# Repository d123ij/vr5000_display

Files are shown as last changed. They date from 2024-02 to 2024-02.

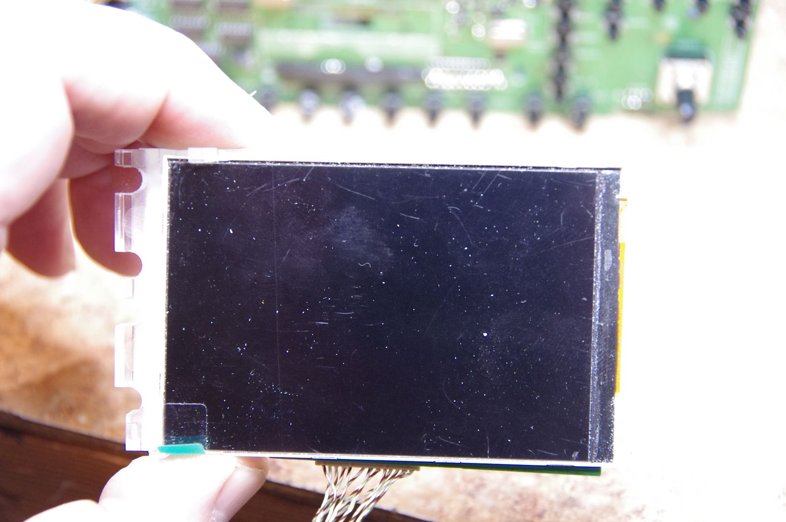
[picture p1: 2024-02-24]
images/IMGP0147 [].JPG

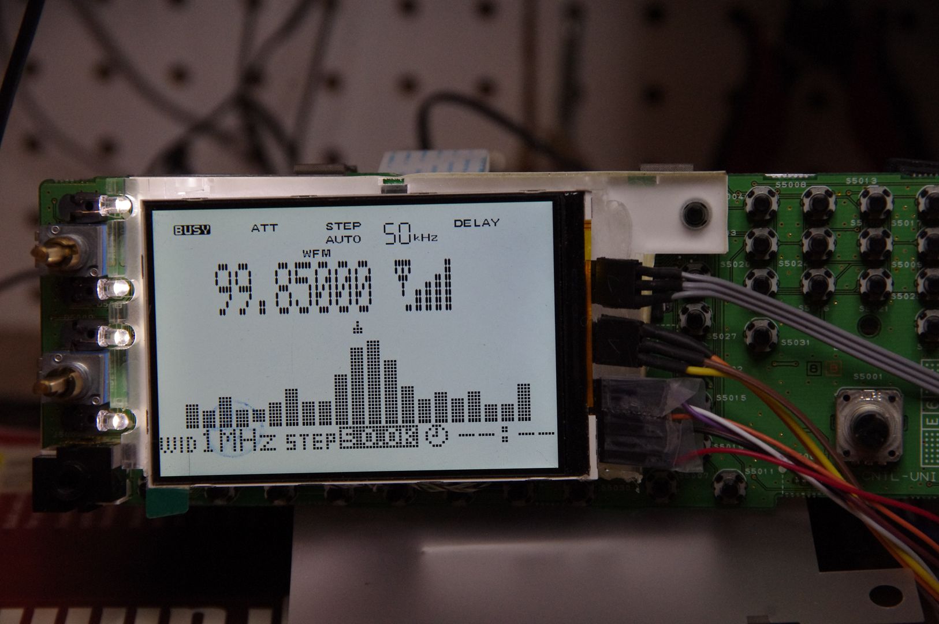
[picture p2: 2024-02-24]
images/IMGP0154 [].JPG

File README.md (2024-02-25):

This project is to create a substitute display unit for Yaesu VR-5000 broad band receiver "famous" for failing LCDs. The design is made possible only because of prior work by kakiralime (this is youtube username). I would not have enough patience to pull this through myself. 
There are three parts to the project:
 - Hardware (PCB)
 - FPGA firmware project
 - RP2040 firmware project

1. PCB project. Pretty simple 2 layer board made with JLCPCB
2. FPGA project is to emulate functionality of NJU6575 IC used in the original LCD and pass data along to the RP2040 that does all the graphics. The vr5000 CPU does use read-modify-write approach when working with the display memory. Therefore, when the original display IC, NJU6575 is removed its buffer has to be simulated. In this project is was done using Lattce LCMXO2-1200HC FPGA ($7). The FPGA has internal flash memory and free tool set is provided from Lattice. It can be programmed using HW-USBN-2A clone from e-bay. The cheapest one at the time of this writing was around $20. In addition to simulating the memory buffer the FPGA also packages and sends data to the rp2040. Communication protocol is one-directional and uses 6 lines all from FPGA to rp2040. There are: CSN, CLK and DATA(3:0). Every transaction has three clock pulses and both edges of the clock are used for the data transfer. Two clocks are used to sent four bytes, the third clock is dummy to make sure rp2040 state machine never get stuck. There is only one command to send page and column number for data transfers. Data transactions are sent one byte per transfer. The FPGA system interface has to handle 5V, which is achieved by using 8 bit level shifter IC to deal with bi-directional data lines. WRN, RDN and A0 signals are input only and dealt with by using a current limiting resistor on the FPGA input. 
3. RP2040 is responsible for displaying data. All the graphic utilities are based on kakiralime's work. I used them pretty much unchanged. The firmware runs on top of FreeRTOS. Communication with the FPGA is done via PIO state machine. rp2040 is a slave, it monitors CSN and CLK signals and inputs data when clock transition is detected. Data are transferred from input FIFOs to memory via two chained DMA channels that operate continuously. I found that using one DMA in conjunction with interrupt is not fast enough and data are lost periodically with that approach. Chaining DMAs solved that. Once data arrived they placed in queue by ISR. One of the background tasks dequeues data and processes incoming commands and data. The data format for the LCD consumption follows the one in kakiralime work to minimize amount of work. I only updated in/out routines for a different CPU and restructured code somewhat. The utilized LCD model is the same, currently ~$10 delivered from AliExpress (I bough it from JR E-Shop). You can see the image from AliExpress in the image section. Programming of the rp2040 was done using debug interface and PI pico module as a debugger. I actually routed debugging connector out of receiver to modify software while operating radio. 
4. This project is not for faint-harted! You should be able to solder QFN packages and trap-door connectors with 0.6 mm pitch. To fit the new unit inside the receiver I reused the original plexiglass block by making a cavity large enough to fit the new PCB, which is fixed to the back of the LCD by sticky tape. Dremel tool is your friend here. The new display dimension is somewhat smaller than original LCD, you can see the space on the right side of the screen unoccupied by the LCD.
5. This design requires two power connections. The 5V power was taken from c5012 as 5v from the LCD connector is there even when the receiver is off. Backlight power was taken from TP5069. The board consumption was around 50-60mA. Backlight current was about 80mA.

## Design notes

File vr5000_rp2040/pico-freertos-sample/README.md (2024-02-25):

# Raspberry Pi Pico Sample application with FreeRTOS

## Introduction

- FreeRTOS kernel library for Pico SDK

## How to make

Pico SDK environment is required.

- Clone this repository with "--recursive" option.
- Type following commands.
    ```
    $ mkdir build
    $ cd build
    $ cmake ..
    $ make
    ```

## License

- MIT (same as FreeRTOS kernel)
  - freertos/ directory
- BSD 3-Clause (same as Pico SDK)
  - others

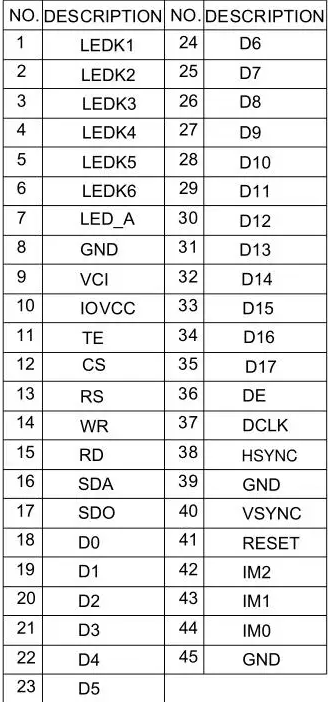
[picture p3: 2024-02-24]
v5000_lcd_rev2_pcb/disp_pinout.png

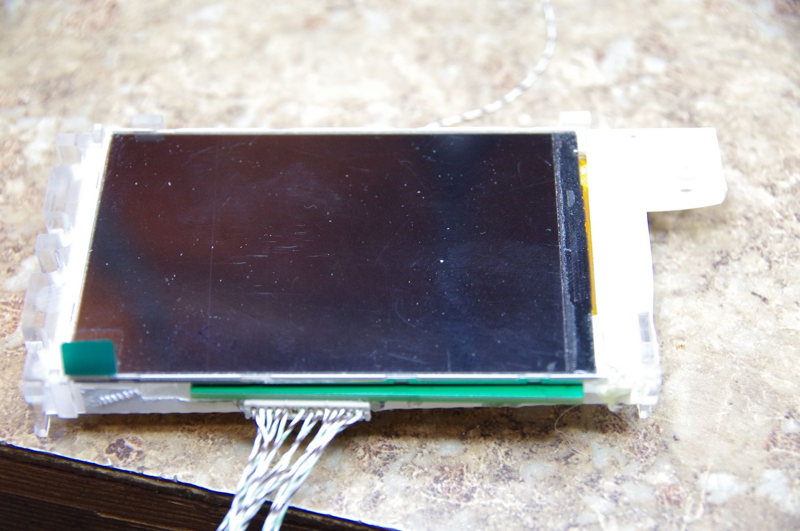
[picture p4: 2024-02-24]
images/IMGP0146 [].JPG

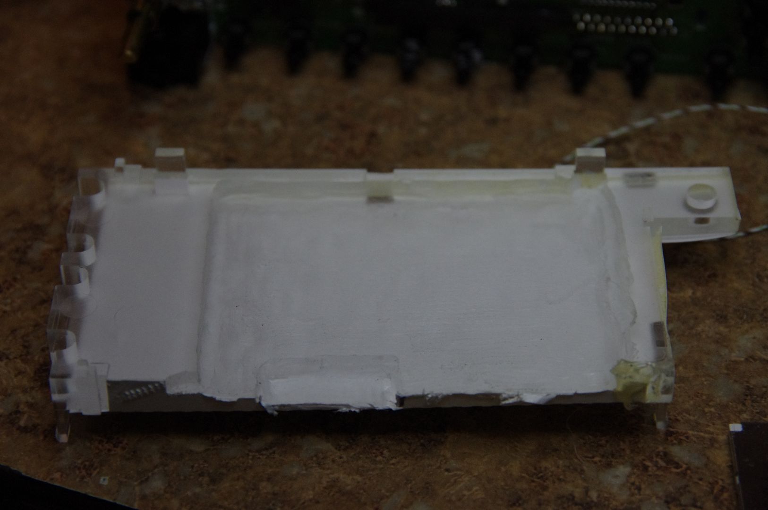
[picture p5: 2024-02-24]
images/IMGP0151 [].JPG

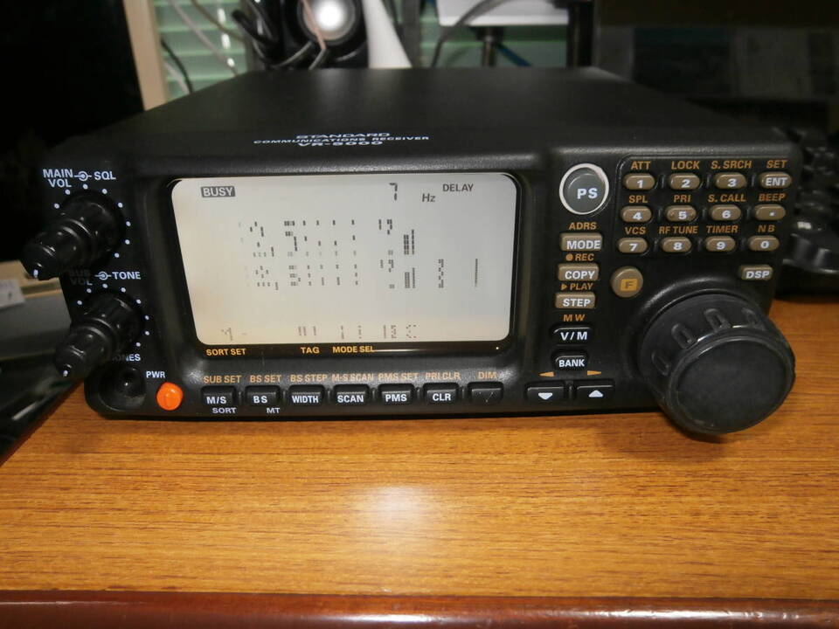
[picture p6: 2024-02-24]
images/s-l960.jpg

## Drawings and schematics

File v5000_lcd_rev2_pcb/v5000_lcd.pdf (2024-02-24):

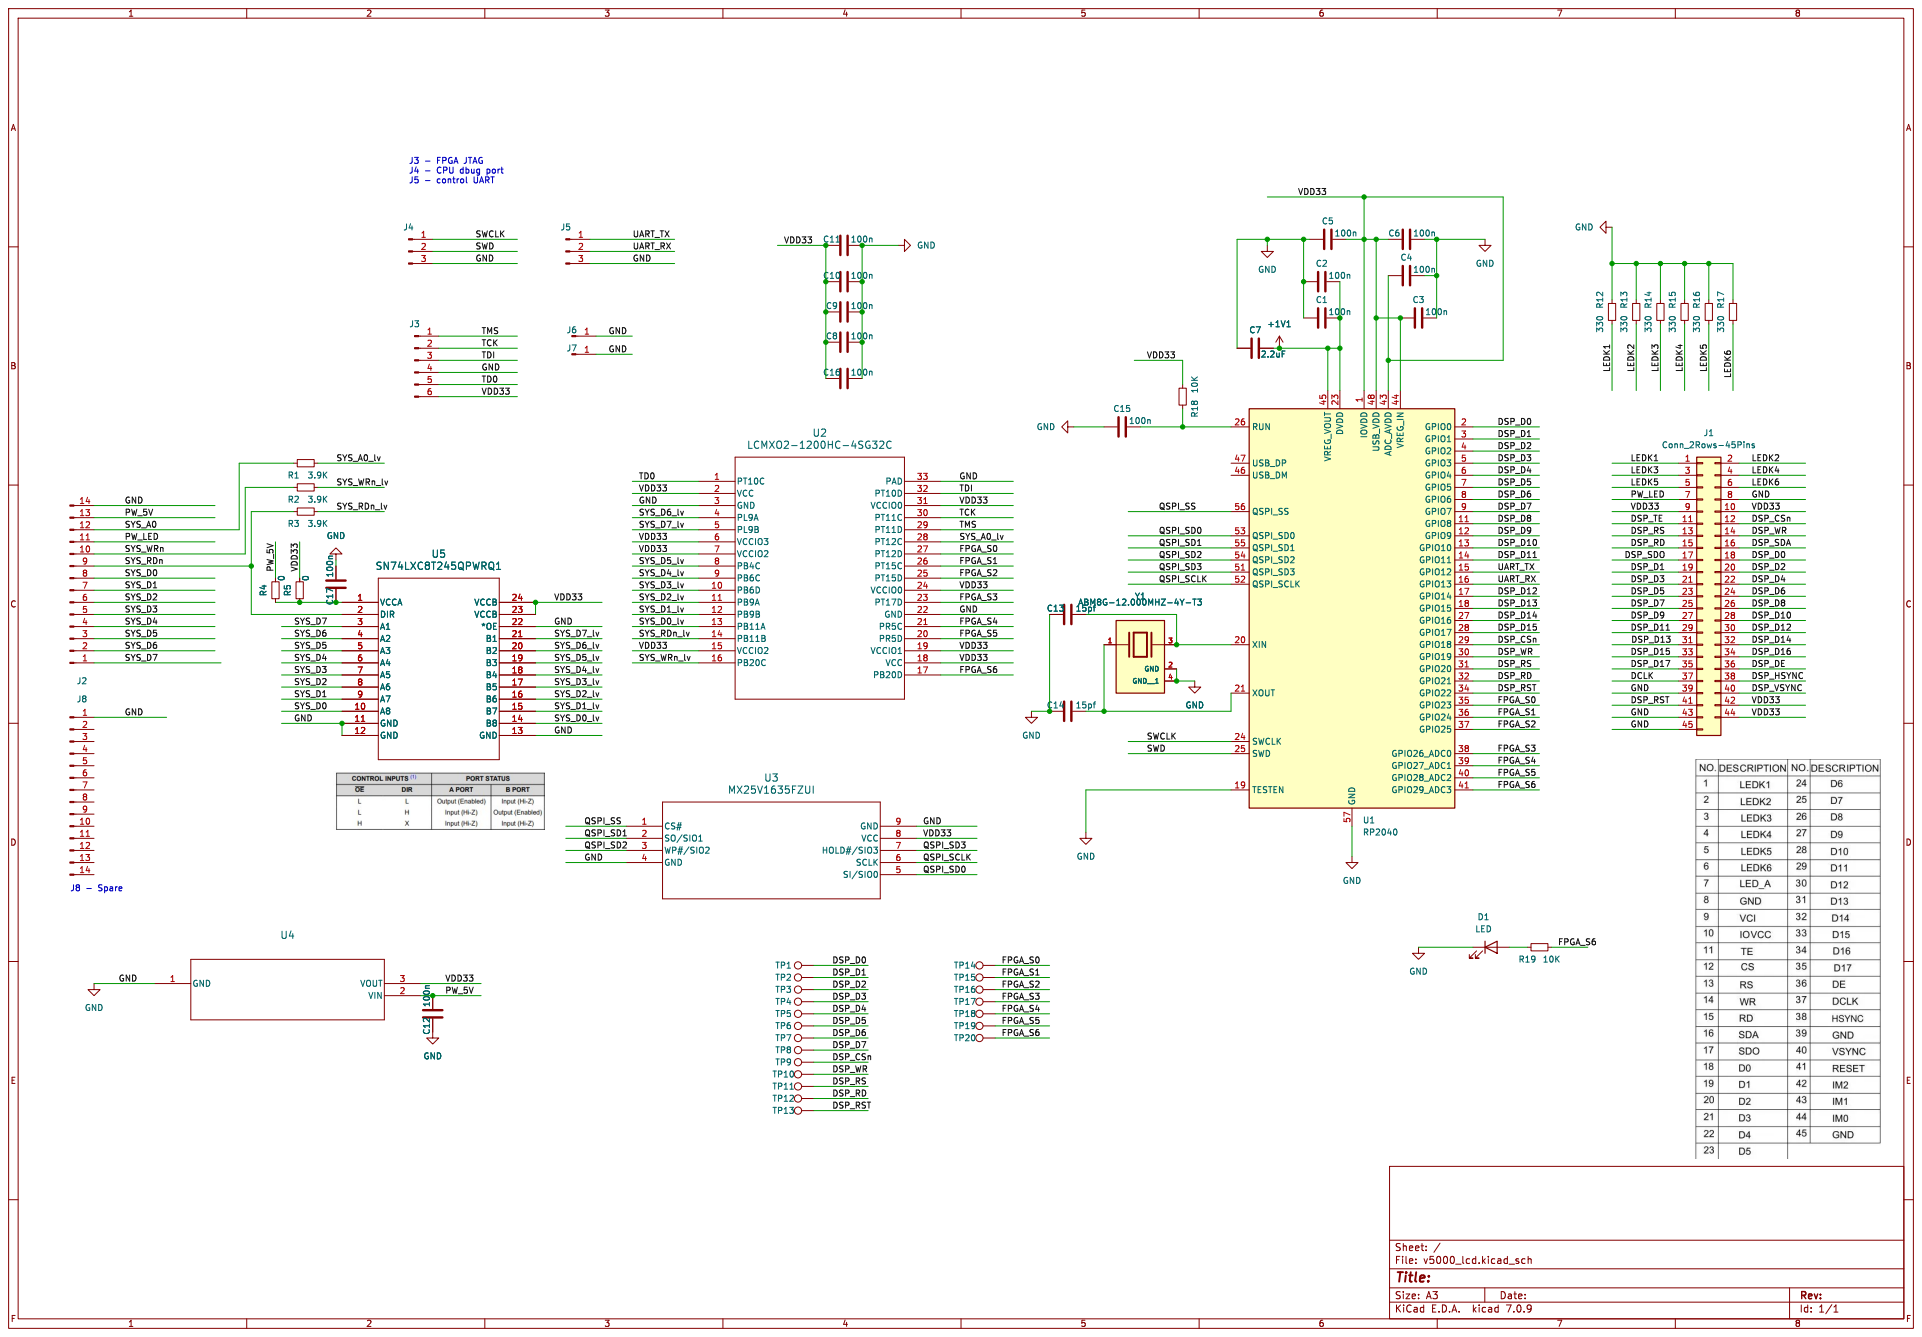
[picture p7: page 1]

1 GPIO8 11 GPIO9 12 GPIO10 13 GPIO11 14 GPIO12 15 GPIO13 16 GPIO14 17 GPIO15 18 TESTEN 19 GPIO0 2 XIN 20 XOUT 21 DVDD 23 SWCLK 24 SWD 25 RUN 26 GPIO16 27 GPIO17 28 GPIO18 29 GPIO1 3 GPIO19 30 GPIO20 31 GPIO21 32 GPIO22 34 GPIO23 35 GPIO24 36 GPIO25 37 GPIO26_ADC0 38 GPIO27_ADC1 39 GPIO2 4 GPIO28_ADC2 40 GPIO29_ADC3 41 ADC_AVDD 43 VREG_IN 44 VREG_VOUT 45 USB_DM 46 USB_DP 47 USB_VDD 48 GPIO3 5 QSPI_SD3 51 QSPI_SCLK 52 QSPI_SD0 53 QSPI_SD2 54 QSPI_SD1 55 QSPI_SS 56 GND 57 GPIO4 6 GPIO5 7 GPIO6 8 GPIO7 9 U1 RP2040 R13 330 C12 100nTP3

0 VCCA 1 A8 10 GND 11 GND 12 GND 13 B8 14 B7 15 B6 16 B5 17 B4 18 B3 19 DIR 2 B2 20 B1 21

Id: 1/1 Title: File: v5000_lcd.kicad_sch Sheet: /

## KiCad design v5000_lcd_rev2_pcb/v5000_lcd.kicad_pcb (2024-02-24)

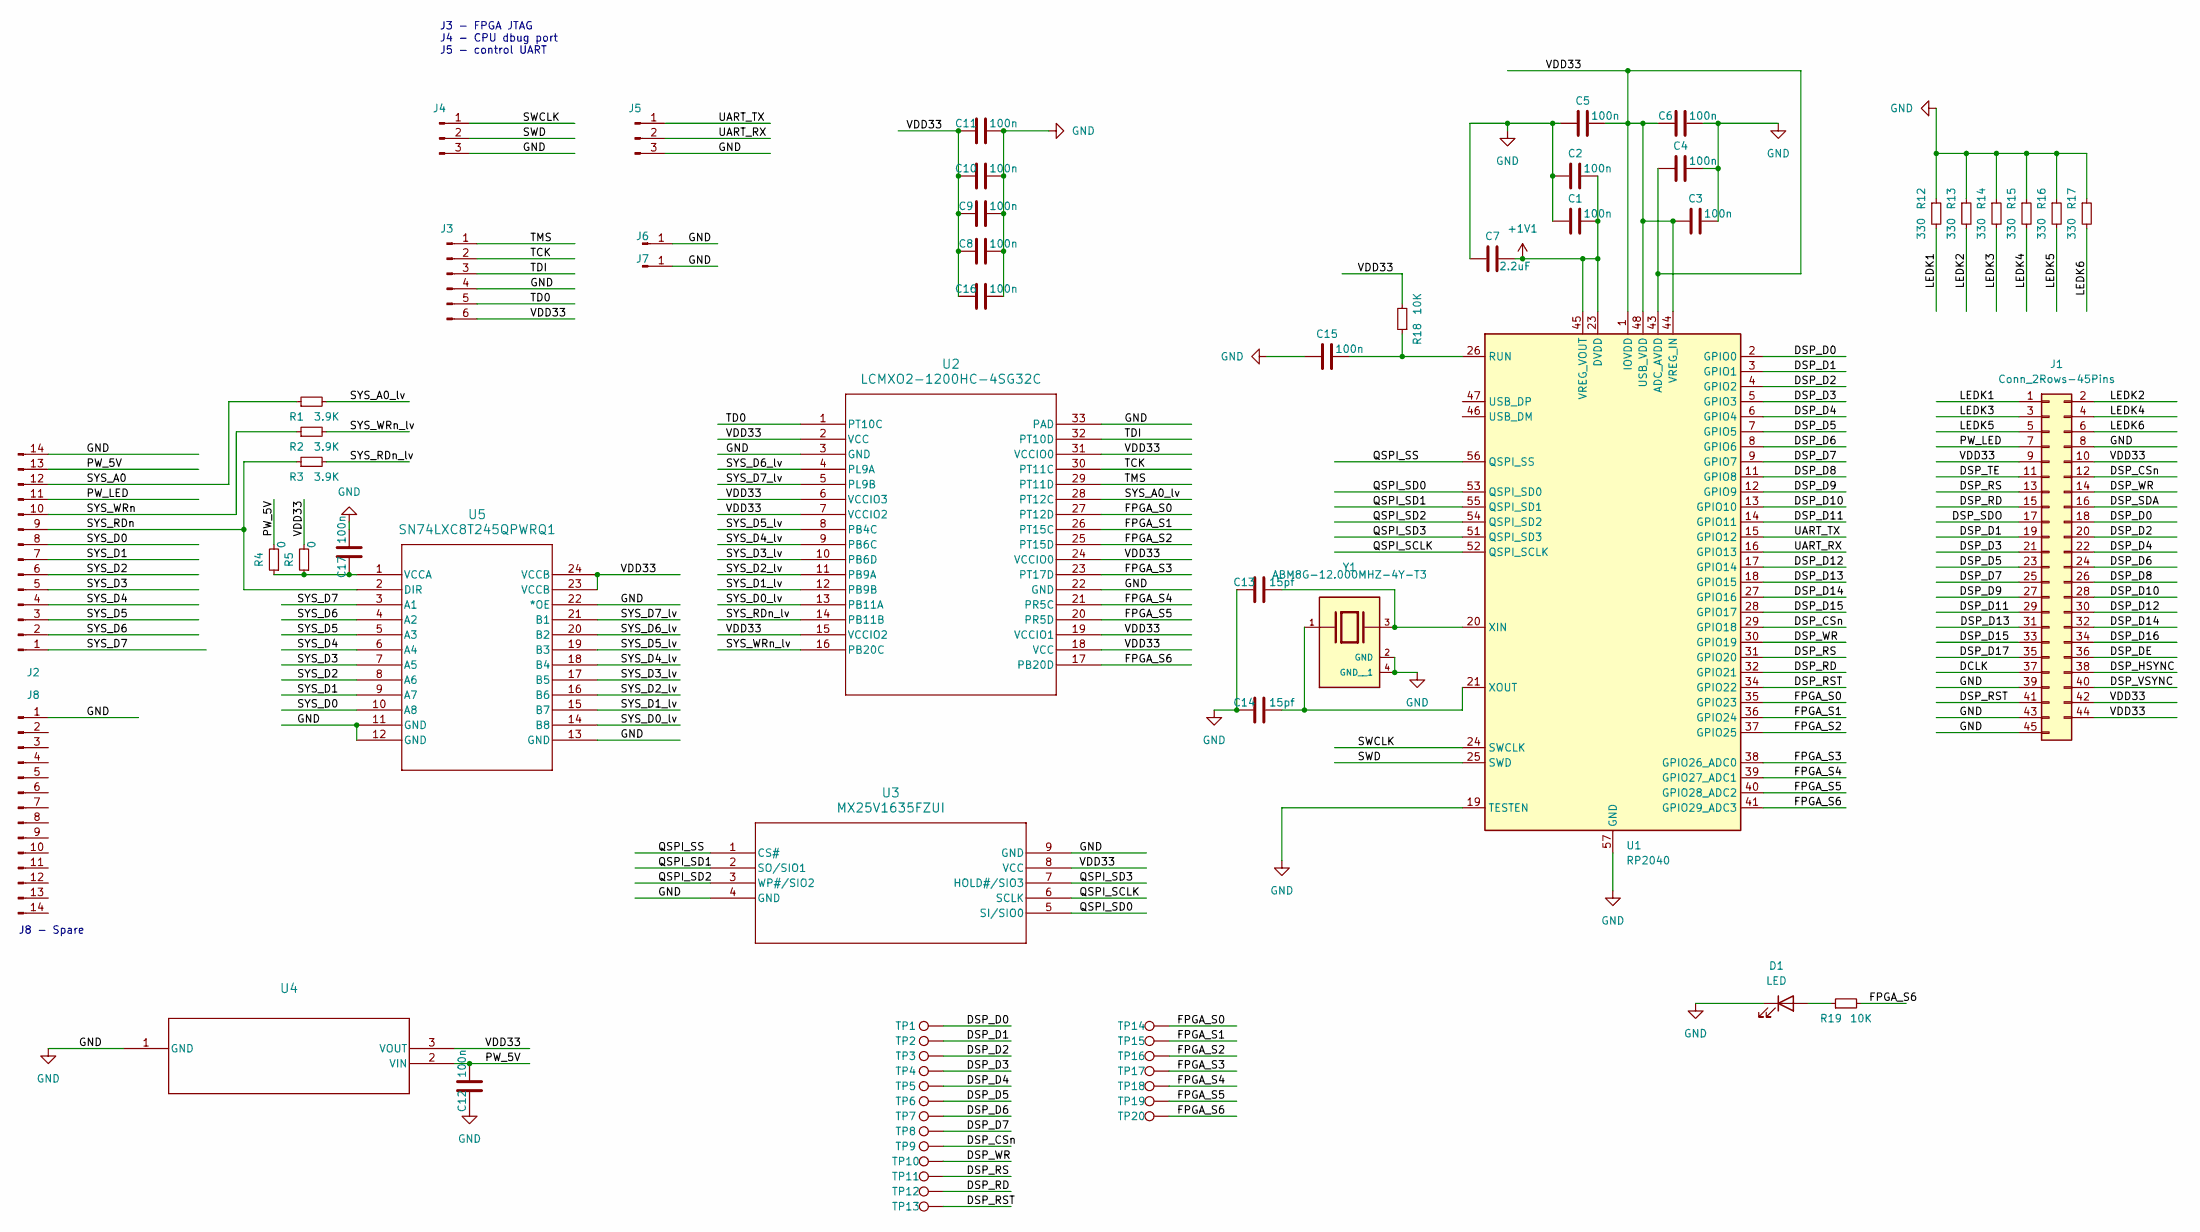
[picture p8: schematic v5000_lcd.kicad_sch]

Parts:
C1, C2, C3, C4, C5, C6, C8, C9, C10, C11, C12, C15, C16, C17: 100n; C_0603_1608Metric
C7: 2.2uF; C_0603_1608Metric
C13, C14: 15pf; C_0603_1608Metric
D1: LED; D_0805_2012Metric
J1: Conn_2Rows-45Pins; CONN_45_FPC_06MM
J2: Conn_01x14_Pin; CON_532611471
J3: Conn_01x06_Pin; PinHeader_1x06_P2.54mm_Vertical
J4, J5: Conn_01x03_Pin; PinHeader_1x03_P2.54mm_Vertical
J6, J7: Conn_01x01_Pin; PinSocket_1x01_P2.54mm_Vertical
J8: Conn_01x14_Pin; PinHeader_2x07_P2.54mm_Vertical
R1, R2, R3: 3.9K; R_0603_1608Metric
R4, R5: 0; R_0603_1608Metric
R12, R13, R14, R15, R16, R17: 330; R_0603_1608Metric
R18, R19: 10K; R_0603_1608Metric
TP1, TP2, TP3, TP4, TP5, TP6, TP7, TP8, TP9, TP10, TP11, TP12, TP13, TP14, TP15, TP16, TP17, TP18, TP19, TP20: TestPoint; tp_small
U1: RP2040; QFN-56-1EP_7x7mm_P0.4mm_EP3.2x3.2mm
U2: LCMXO2-1200HC-4SG32C; QFN32_SG32C_LAT
U3: MX25V1635FZUI; 8-USON_2X3_MAC
U4: MCP1700T-1202E/MB; SOT-89_3MC_MCH
U5: SN74LXC8T245QPWRQ1; TSSOP24_PW_TEX
Y1: ABM8G-12.000MHZ-4Y-T3; XTAL_ABM8G-12.000MHZ-4Y-T3; PARTREV 08.13.15

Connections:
+1V1: C1.2, C2.2, C7.2, U1.23 (DVDD), U1.45 (VREG_VOUT), U1.50 (DVDD)
/DCLK: J1.37
/DSP_CSn: J1.12, TP9.1, U1.29 (GPIO18)
/DSP_D0: J1.18, TP1.1, U1.2 (GPIO0)
/DSP_D1: J1.19, TP2.1, U1.3 (GPIO1)
/DSP_D2: J1.20, TP3.1, U1.4 (GPIO2)
/DSP_D3: J1.21, TP4.1, U1.5 (GPIO3)
/DSP_D4: J1.22, TP5.1, U1.6 (GPIO4)
/DSP_D5: J1.23, TP6.1, U1.7 (GPIO5)
/DSP_D6: J1.24, TP7.1, U1.8 (GPIO6)
/DSP_D7: J1.25, TP8.1, U1.9 (GPIO7)
/DSP_D8: J1.26, U1.11 (GPIO8)
/DSP_D9: J1.27, U1.12 (GPIO9)
/DSP_D10: J1.28, U1.13 (GPIO10)
/DSP_D11: J1.29, U1.14 (GPIO11)
/DSP_D12: J1.30, U1.17 (GPIO14)
/DSP_D13: J1.31, U1.18 (GPIO15)
/DSP_D14: J1.32, U1.27 (GPIO16)
/DSP_D15: J1.33, U1.28 (GPIO17)
/DSP_D16: J1.34
/DSP_D17: J1.35
/DSP_DE: J1.36
/DSP_HSYNC: J1.38
/DSP_RD: J1.15, TP12.1, U1.32 (GPIO21)
/DSP_RS: J1.13, TP11.1, U1.31 (GPIO20)
/DSP_RST: J1.41, TP13.1, U1.34 (GPIO22)
/DSP_SDA: J1.16
/DSP_SDO: J1.17
/DSP_TE: J1.11
/DSP_VSYNC: J1.40
/DSP_WR: J1.14, TP10.1, U1.30 (GPIO19)
/FPGA_S0: TP14.1, U1.35 (GPIO23), U2.27 (PT12D)
/FPGA_S1: TP15.1, U1.36 (GPIO24), U2.26 (PT15C)
/FPGA_S2: TP16.1, U1.37 (GPIO25), U2.25 (PT15D)
/FPGA_S3: TP17.1, U1.38 (GPIO26_ADC0), U2.23 (PT17D)
/FPGA_S4: TP18.1, U1.39 (GPIO27_ADC1), U2.21 (PR5C)
/FPGA_S5: TP19.1, U1.40 (GPIO28_ADC2), U2.20 (PR5D)
/FPGA_S6: R19.2, TP20.1, U1.41 (GPIO29_ADC3), U2.17 (PB20D)
/LEDK1: J1.1, R12.2
/LEDK2: J1.2, R13.2
/LEDK3: J1.3, R14.2
/LEDK4: J1.4, R15.2
/LEDK5: J1.5, R16.2
/LEDK6: J1.6, R17.2
/PW_5V: C12.2, J2.13, R4.2, U4.2 (VIN)
/PW_LED: J1.7, J2.11
/QSPI_SCLK: U1.52 (QSPI_SCLK), U3.6 (SCLK)
/QSPI_SD0: U1.53 (QSPI_SD0), U3.5 (SI/SIO0)
/QSPI_SD1: U1.55 (QSPI_SD1), U3.2 (SO/SIO1)
/QSPI_SD2: U1.54 (QSPI_SD2), U3.3 (WP#/SIO2)
/QSPI_SD3: U1.51 (QSPI_SD3), U3.7 (HOLD#/SIO3)
/QSPI_SS: U1.56 (QSPI_SS), U3.1 (CS#)
/SWCLK: J4.1, U1.24 (SWCLK)
/SWD: J4.2, U1.25 (SWD)
/SYS_A0: J2.12, R1.1
/SYS_A0_lv: R1.2, U2.28 (PT12C)
/SYS_D0: J2.8, U5.10 (A8)
/SYS_D0_lv: U2.13 (PB11A), U5.14 (B8)
/SYS_D1: J2.7, U5.9 (A7)
/SYS_D1_lv: U2.12 (PB9B), U5.15 (B7)
/SYS_D2: J2.6, U5.8 (A6)
/SYS_D2_lv: U2.11 (PB9A), U5.16 (B6)
/SYS_D3: J2.5, U5.7 (A5)
/SYS_D3_lv: U2.10 (PB6D), U5.17 (B5)
/SYS_D4: J2.4, U5.6 (A4)
/SYS_D4_lv: U2.9 (PB6C), U5.18 (B4)
/SYS_D5: J2.3, U5.5 (A3)
/SYS_D5_lv: U2.8 (PB4C), U5.19 (B3)
/SYS_D6: J2.2, U5.4 (A2)
/SYS_D6_lv: U2.4 (PL9A), U5.20 (B2)
/SYS_D7: J2.1, U5.3 (A1)
/SYS_D7_lv: U2.5 (PL9B), U5.21 (B1)
/SYS_RDn: J2.9, R3.1, U5.2 (DIR)
/SYS_RDn_lv: R3.2, U2.14 (PB11B)
/SYS_WRn: J2.10, R2.1
/SYS_WRn_lv: R2.2, U2.16 (PB20C)
/TCK: J3.2, U2.30 (PT11C)
/TD0: J3.5, U2.1 (PT10C)
/TDI: J3.3, U2.32 (PT10D)
/TMS: J3.1, U2.29 (PT11D)
/UART_RX: J5.2, U1.16 (GPIO13)
/UART_TX: J5.1, U1.15 (GPIO12)
/VDD33: C3.1, C4.1, C5.2, C6.1, C8.1, C9.1, C10.1, C11.1, C16.1, J1.9, J1.10, J1.42, J1.44, J3.6, R5.2, R18.2, U1.1 (IOVDD), U1.10 (IOVDD), U1.22 (IOVDD), U1.33 (IOVDD), U1.42 (IOVDD), U1.43 (ADC_AVDD), U1.44 (VREG_IN), U1.48 (USB_VDD), U1.49 (IOVDD), U2.2 (VCC), U2.6 (VCCIO3), U2.7 (VCCIO2), U2.15 (VCCIO2), U2.18 (VCC), U2.19 (VCCIO1), U2.24 (VCCIO0), U2.31 (VCCIO0), U3.8 (VCC), U4.3 (VOUT), U5.23 (VCCB), U5.24 (VCCB)
GND: C1.1, C2.1, C3.2, C4.2, C5.1, C6.2, C7.1, C8.2, C9.2, C10.2, C11.2, C12.1, C13.1, C14.1, C15.1, C16.2, C17.2, D1.1 (K), J1.8, J1.39, J1.43, J1.45, J2.14, J3.4, J4.3, J5.3, J6.1, J7.1, J8.1, R12.1, R13.1, R14.1, R15.1, R16.1, R17.1, U1.19 (TESTEN), U1.57 (GND), U2.3 (GND), U2.22 (GND), U2.33 (PAD), U3.4 (GND), U3.9 (GND), U4.1 (GND), U5.11 (GND), U5.12 (GND), U5.13 (GND), U5.22 (*OE), Y1.2 (GND), Y1.4 (GND__1)
unnamed: D1.2 (A), R19.1
unnamed: C15.2, R18.1, U1.26 (RUN)
unnamed: C13.2, U1.20 (XIN), Y1.3
unnamed: C14.2, U1.21 (XOUT), Y1.1
unnamed: C17.1, R4.1, R5.1, U5.1 (VCCA)

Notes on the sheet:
J3 - FPGA JTAG J4 - CPU dbug port J5 - control UART
J8 - Spare

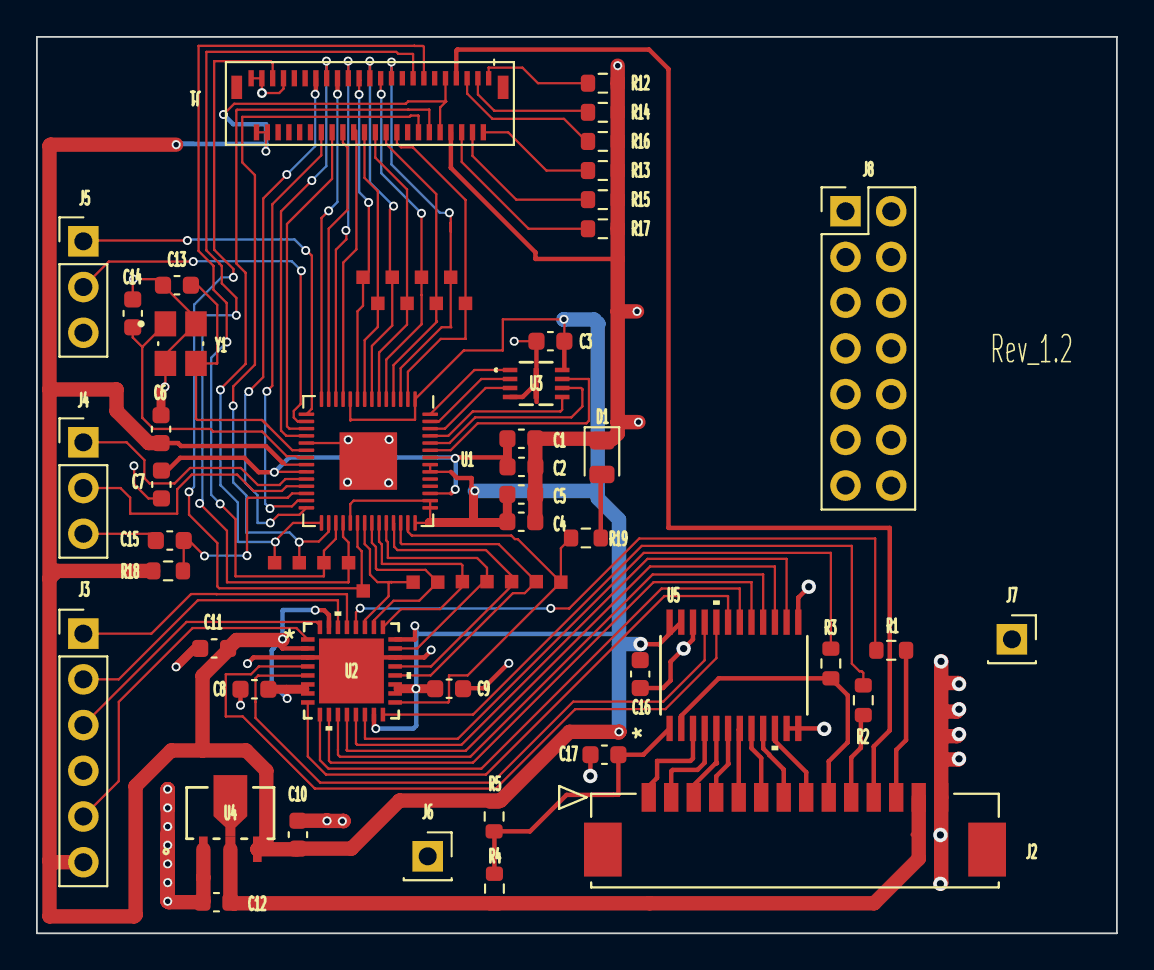
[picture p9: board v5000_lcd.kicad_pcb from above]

Board: 2 copper layers, 60.0 x 49.8 mm, 65 parts (0 on the bottom side), 80 nets.

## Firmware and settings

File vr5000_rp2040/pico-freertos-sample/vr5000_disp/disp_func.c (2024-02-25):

#include "disp_func.h"
#include "hardware/gpio.h"
#include <FreeRTOS.h>
#include <task.h>
#include <queue.h>
#include "disp_font.h"


#define cGLB_Y_OFFSET    -8
uint8_t col_addr = 0;
uint8_t page_addr = 0;
uint8_t page_addr_1 = 0;
uint8_t pix_buff_A[50][160];
uint8_t pix_buff_U[50][160];

uint tst = 0;
#define cN_DISP_PINS 21

uint8_t disp_pins[cN_DISP_PINS]={0,1,2,3,4,5,6,7,8,9,10,11,14,15,16,17,18,19,20,21,22};
uint8_t page2disp_pos[5]={1,0,3,2,4};

/*                                      
pin 18 - CSN, index 16 - active 0
pin 19 - WR, index 17 - active 0
pin 20 - RS, index 18 - 0 - register access, 1- data
pin 21 - RD, index 19 - active 0
pin 22 - RST, index 20 - active 0
*/

#define cCSN_PIN 16
#define cWR_PIN  17
#define cRS_PIN  18
#define cRD_PIN  19
#define cRST_PIN 20

#define cNOP     1F;

void init_disp()
{
   for (int i=0;i<40;i++)
     for (int j=0;j<160;j++)
     {
       pix_buff_A[i][j]=2;
       pix_buff_U[i][j]=0;
     }
     
}
//this function interprets NJU6575 commands and does LCD memroy buffer writes
uint8_t parse_data_cmd(uint16_t dt16)
{
  uint8_t result = 0;
  //do nothing for now
  int16_t cmd, dt;
  uint8_t indx_x, indx_y;
  uint8_t tmp, val_b;
  cmd = (dt16>>4)&0xF;//extract command;
  dt =((dt16>>4)&0xF0)|((dt16>>12)&0xF);
  switch(cmd)
  {
    case(cCMD_PADR)://unused all data are packed in cCMD_COLL command
      //page_addr_1=(dt&0x7);
      //if (page_addr>cMX_PAGE) page_addr=cMX_PAGE;
    break;
    
    case(cCMD_COLH)://called before setting low address //unused all data are packed in cCMD_COLL command
      //col_addr&=0x0F;
      //col_addr|=(dt&0xF)<<4;
    break;
    //FPGA compacts page address, low and high col addresses into single command
    case(cCMD_COLL)://this command transfers the page, and full column address from FPGA
      page_addr =  (dt16)&0x7;
      if (page_addr_1!=page_addr)
        page_addr_1=page_addr;
      if (page_addr>cMX_PAGE) page_addr=cMX_PAGE;
      col_addr=dt&0xFF;
    break;
    
    case(cCMD_DATA):
      for ( int i = 7 ; (i + 7) >= 7 ; i--) 
      {
        indx_x = page2disp_pos[page_addr] * 8 +(7 - i);
        tmp = (dt >> i)&1;
        val_b = pix_buff_A[indx_x][col_addr];
        if ((val_b&1)!=tmp) pix_buff_U[indx_x][col_addr]=1;
        pix_buff_A[indx_x][col_addr] = tmp;
      }
      if (page2disp_pos[page_addr]==3)
        col_addr = (col_addr>118)?119:col_addr+1;
      else
        col_addr = (col_addr>159)?159:col_addr+1;
    break;
    
    case(cCMD_END_RMW):
      result = 0;//not used
    break;
    
    default://do nothing
      tst = dt16;
  }
  return result;
}

void init_disp_pins()
{
  //set pins to output
  for (int i=0;i<cN_DISP_PINS;i++)
  {
    uint8_t pin_n = disp_pins[i];
    gpio_init(pin_n); gpio_set_dir(pin_n, GPIO_OUT);
  }
  for (int i=0;i<16;i++) gpio_put(disp_pins[i], 0);//set data to 0
  gpio_put(disp_pins[cRST_PIN],1);
  gpio_put(disp_pins[cCSN_PIN],1);
  gpio_put(disp_pins[cWR_PIN] ,1);
  gpio_put(disp_pins[cRD_PIN] ,1);
  gpio_put(disp_pins[cRS_PIN] ,1);
  rst_disp();
}

void rst_disp()
{
  gpio_put(disp_pins[cRST_PIN],0);
  vTaskDelay(pdMS_TO_TICKS(1)); //1ms delay
  gpio_put(disp_pins[cRST_PIN],1);
  vTaskDelay(pdMS_TO_TICKS(5)); //1ms delay
}



//bit 0 - CSN
//bit 1 - WR
//bit 2 - RS - register select
//RD and RST are not used for the interface
void inline write_cmd_pins(uint32_t cmd)
{
  uint32_t cmd_out = (cmd&0x7)<<18;//
  gpio_put_masked(0x0001C0000, cmd_out);
}

void inline lcd_write_cmd(uint32_t dt)
{
  gpio_put_masked(0x000000FF, dt);
  gpio_put_masked(0x0001C0000,0x000000000); //write_cmd_pins(0b000);
  gpio_put_masked(0x0001C0000,0x000140000); //write_cmd_pins(0b010);;
  gpio_put_masked(0x0001C0000,0x0001C0000); //write_cmd_pins(0b111);
}

void inline lcd_write_data(uint32_t dt)
{
  uint32_t dt_tmp = (dt&80)?0x0003CF00|(uint8_t)dt:(uint8_t)dt;
  gpio_put_masked(0x0003CFFF, dt_tmp);
  gpio_put_masked(0x0001C0000,0x000100000); //write_cmd_pins(0b100);
  gpio_put_masked(0x0001C0000,0x000180000); //write_cmd_pins(0b110);
  gpio_put_masked(0x0001C0000,0x0001C0000); //write_cmd_pins(0b111);
}



//skips gpio 12 and 13 mapped to UART, moves bits 12-15 to 14-17
void write_dt(uint32_t dt)
{
  uint32_t dt_tmp = (dt&80)?0x0003CF00|(uint8_t)dt:(uint8_t)dt;
  gpio_put_masked(0x0003CFFF, dt_tmp);
}
//skips gpio 12 and 13 mapped to UART, moves bits 12-15 to 14-17
void write_cmd(uint32_t dt)
{
  gpio_put_masked(0x000000FF, dt);
}

void tst_dt(uint16_t dt)
{
  uint32_t tmp_dt = ((dt&0xFF)<<8)|(dt&0xFF);
  uint32_t dt_tmp = (tmp_dt << 2)&0x0003C000;//clear bits 12 and 13, likely not needed;
  uint32_t dt_out = tmp_dt&0x00003FFF;
  dt_out|=dt_tmp;
  gpio_put_masked(0x0003CFFF, dt_out);
}

/**
 * @brief     Write LCD Register in
 * @param    reg   Register number
 * @param    data  The value to write to the register
 * @retval   none
*/

static void inline lcd_write_ram_start(void)
{
    lcd_write_cmd(0x2C);
}

static void inline lcd_write_ram(uint16_t rgb_color)
{
    lcd_write_data(rgb_color);
}

/**
 * @breif	LCD Fill a rectangular area
 * @param   x1 x Direction starting coordinates
 * @param   x2 x Direction termination coordinates
 * @param   y1 y Direction starting coordinates
 * @param   y2 y Direction termination coordinates
 * @param	color  Color
 * @retval	none
 */
void inline lcd_fill(uint16_t x1, uint16_t y1, uint16_t x2, uint16_t y2, uint16_t color)
{
    uint32_t i;
    uint32_t size = (x2 - x1 + 1) * (y2 - y1 + 1);
    lcd_set_rectangular_area(x1, y1, x2, y2);
    lcd_write_ram_start();
    for(i = 0; i < size; i++)
    {
      lcd_write_ram(color);
    }
}

/**
 * @breif	LCD Fill_s a rectangular XY Size
 * @param   x1 x Direction starting coordinates
 * @param   x2 x Size
 * @param   y1 y Direction starting coordinates
 * @param   y2 y Size
 * @param	color  Color
 * @retval  none
 */
void inline  lcd_fill_s(uint16_t x1, uint16_t y1, uint16_t x2, uint16_t y2, uint16_t color)
{
  lcd_fill(x1, y1, (x1 + x2 -1), (y1 + y2 -1), color);
}

/**
 * @breif	LCD Fill_s a rectangular XY Size
 * @param   x1 x Direction starting coordinates
 * @param   x2 x Size
 * @param   y1 y Direction starting coordinates
 * @param   y2 y Size
 * @param	color  Color
 * @retval	none
 */

void inline lcd_set_rectangular_area(uint16_t x1, uint16_t y1,uint16_t x2, uint16_t y2)
{
    y1 +=cGLB_Y_OFFSET;
    y2 +=cGLB_Y_OFFSET;
    int32_t act_x1 = x1 < 0 ? 0 : x1;
    int32_t act_y1 = y1 < 0 ? 0 : y1;

    int32_t act_x2 = x2 > 480 - 1 ? 480 - 1 : x2;
    int32_t act_y2 = y2 > 320 - 1 ? 320 - 1 : y2;

    lcd_write_cmd(0x2A); //set_column_address
    lcd_write_data(act_x1 >> 8); // starts frame buffer address
    lcd_write_data(0x00FF & act_x1);
    lcd_write_data(act_x2 >> 8);
    lcd_write_data(0x00FF & act_x2);

    lcd_write_cmd(0x2B); //set_page_address
    lcd_write_data(act_y1 >> 8); // starts frame buffer address
    lcd_write_data(0x00FF & act_y1);
    lcd_write_data(act_y2 >> 8);
    lcd_write_data(0x00FF & act_y2);
}
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

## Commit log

2024-02-24 PCB project for Yaesu vr5000 display module
    [v5000_lcd.kicad_pcb, v5000_lcd.kicad_sch]
2024-02-24 Added schematic PDF
